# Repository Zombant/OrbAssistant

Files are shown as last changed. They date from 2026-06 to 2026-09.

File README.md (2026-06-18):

# Orb Assistant

This device is intended to be used with Home Assistant as an Assist Satellite entity. It includes a virtual switch to turn off the assistant (which can prevent midnight jumpscares). In this case you can just use it as a cool RGB light.

### Home Assistant setup

Some setup is required on home assistant

1. Add the ESPHome device (ESPHome has instructions)

2. Create an automation called _Restore Orb LED_ and insert the contents of restore_orb_led.yaml.

3. Create a script called _Store Current Orb LED_ and insert the contents of _store_current_orb_led.yaml_.

4. Create a voice assistant pipeline:
    1. Choose a conversation agent, STT, and TTS. I used Gemini (yes I know)
    2. Install the openwakeword app and add the service
    3. Copy _I_Ponder.tflite_ to _/share/openwakeword_. You may want to install the Terminal & SSH app to do this
    4. Alternatively you can train your own wake word with this [notebook](https://colab.research.google.com/drive/1q1oe2zOyZp7UsB3jJiQ1IFn8z5YfjwEb?usp=sharing)
5. For the orb personality, I added this text (partially AI generated) to the voice assistant instructions:
```
You are a voice assistant for Home Assistant.
Answer questions about the world truthfully.
Answer in plain text. Keep it simple and to the point.
You will also take the personality of a mystical orb/crystal ball. Your name is the "Orb of Nirud". You will not mention home assistant as that breaks the immersion. Instead, you are here to aid me in my wizard tower.

CRITICAL RULE FOR FALSE ACTIVATIONS:
The Speech-to-Text engine frequently picks up background noise and hallucinates phrases when the user hasn't actually spoken. If the user's input is very short and lacks a clear command or question (for example: "Thank you.", "Okay.", "Yeah.", "Hello.", or empty space), assume it was a false activation.

If you suspect a false activation, DO NOT greet the user. DO NOT ask how you can help. DO NOT use any question marks. You must respond with exactly: "False alarm." or "I didn't catch that." The conversation has ended
```

### BOM
- 1x INMP441 I2S Microphone
- 1x ESP32-C3-Super Mini
- 1x MAX98357A I2S Class D Amplifier
- 1x 3W 4Ohm Speaker
- 1x WS2812B RGB LED Ring (12 bits) [Link](https://www.amazon.com/dp/B0B2D69NQ4)
- 1x 3D-printed frame
- 1x 3D-printed LED cradle
- 1x Frosted glass light globe

### Construction
I soldered wires to the LED ring before pushing it into the LED cradle.

Everything is soldered to a standard perfboard.

I shoved everything in the base with the speaker pointed downward over the hole and the microphone angled towards a set of small holes.

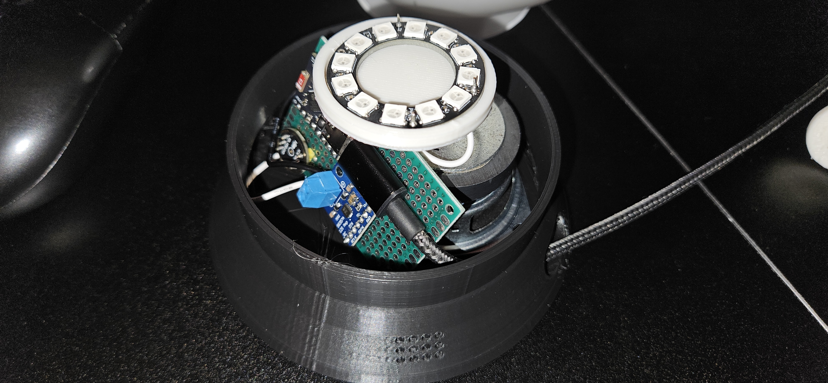
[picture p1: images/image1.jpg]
Inside the orb


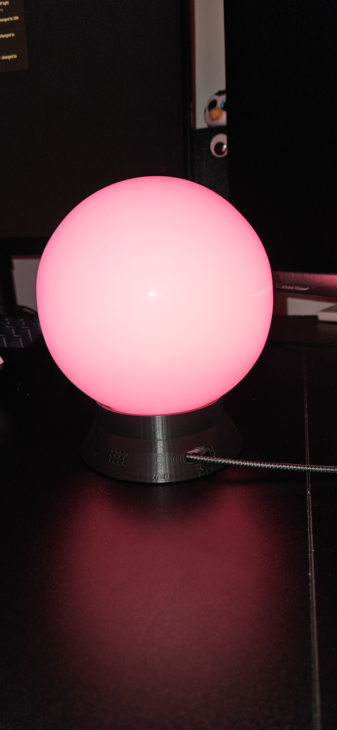
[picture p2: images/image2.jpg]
The orb


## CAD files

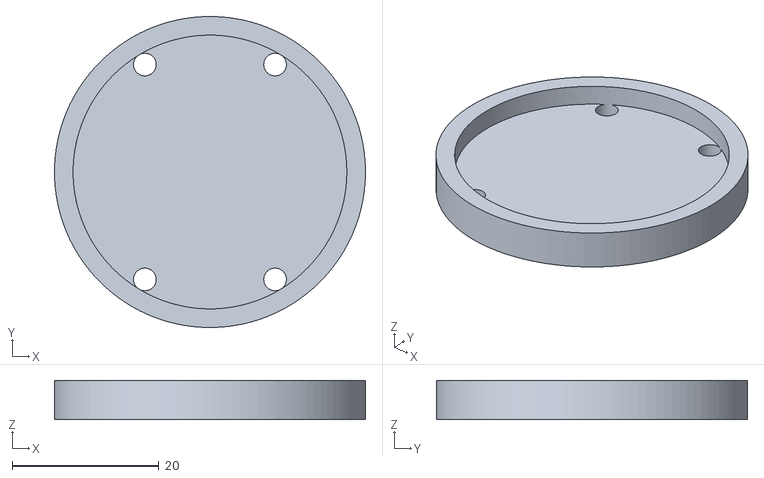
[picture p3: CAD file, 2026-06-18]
STLs/Orb_Cradle.stl
42.4 x 42.4 x 5.33

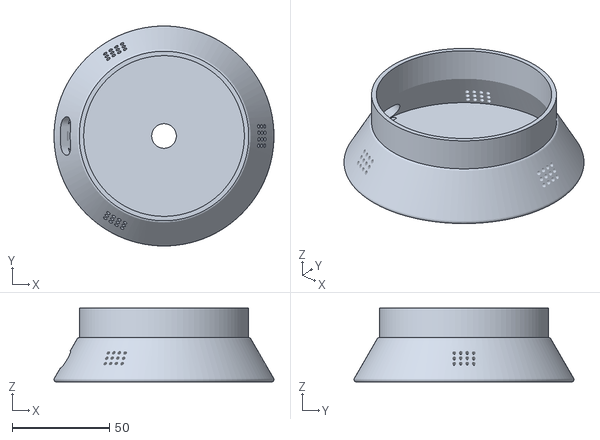
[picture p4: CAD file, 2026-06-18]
STLs/Orb_Frame_Tall_Flat.stl
113.3 x 113.3 x 38.1

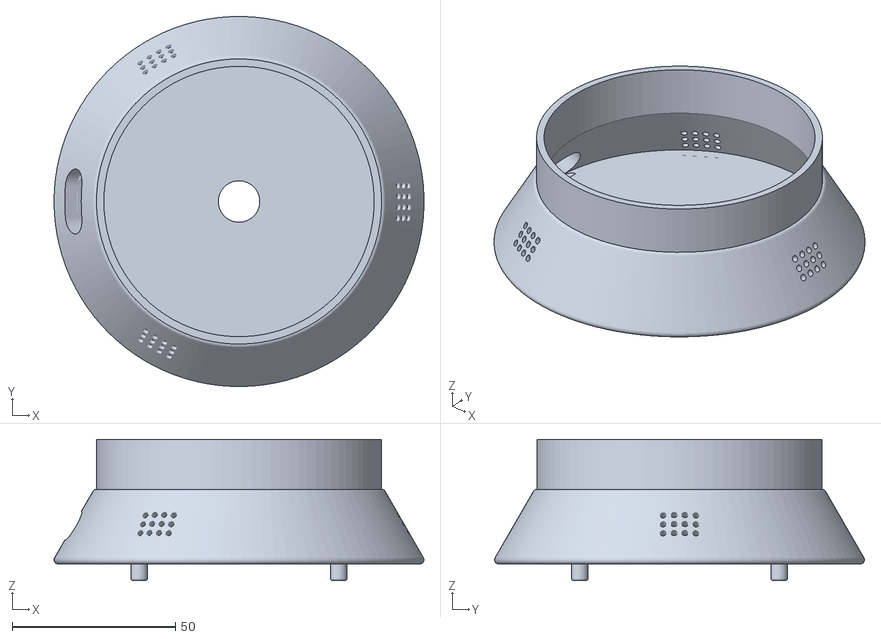
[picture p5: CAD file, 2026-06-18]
STLs/Orb_Frame_Tall.stl
113.3 x 113.3 x 43.2

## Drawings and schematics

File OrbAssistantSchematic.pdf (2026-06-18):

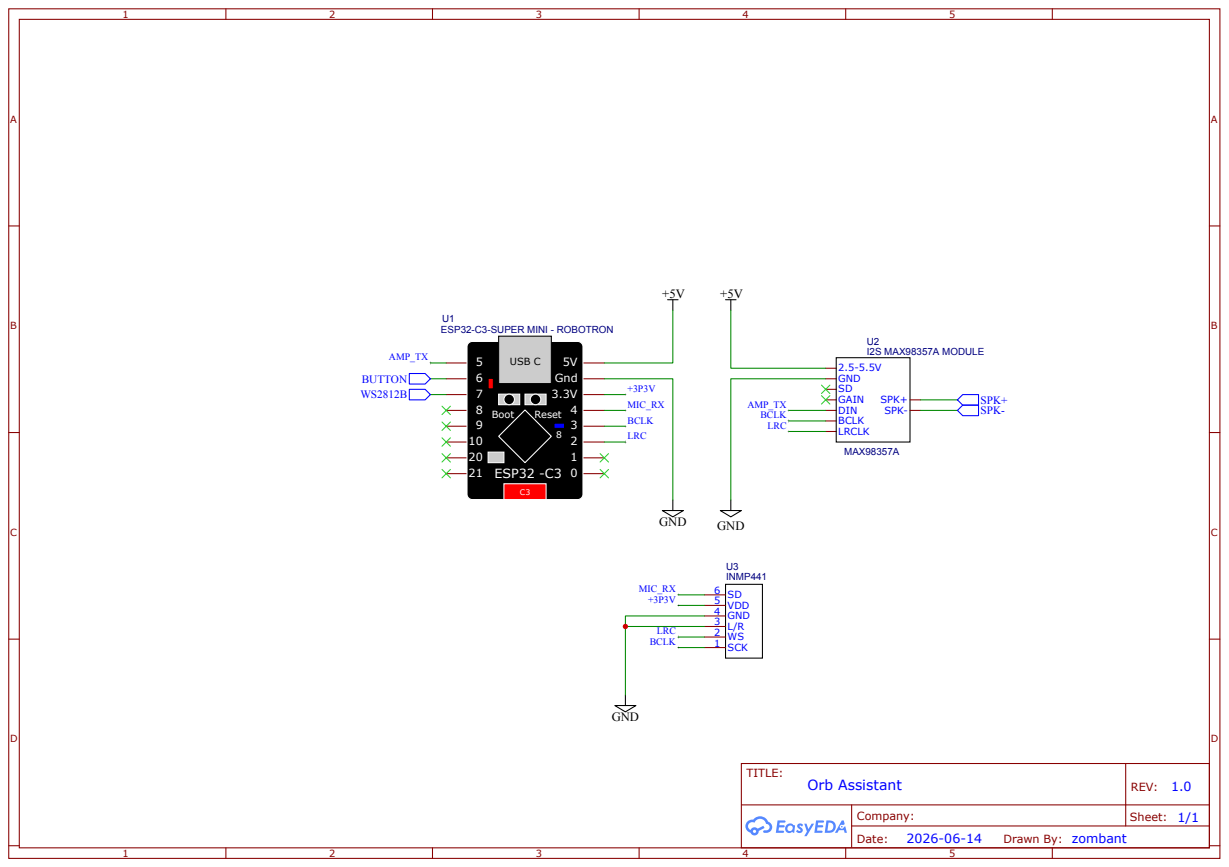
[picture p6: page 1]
TITLE:; Orb Assistant; REV: 1.0; Date:; Sheet: 1/1; Company:; GND; ESP32 -C3; USB C; Gnd; ResetBoot; I2S MAX98357A MODULE; MAX98357A; LRCLK; BCLK; DIN; GAIN; SPK-; SPK+; INMP441; L/R 3 WS 2 SCK 1; SD 6 VDD 5 GND 4; LRC; MIC_RX; BCLK LRC; AMP_TX; BUTTON

ESP32-C3-SUPER MINI - ROBOTRON

Drawn By: zombant

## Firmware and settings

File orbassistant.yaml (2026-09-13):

esphome:
  name: orbassistant
  friendly_name: OrbAssistant
  on_boot:
    - priority: -100
      then:
        - wait_until: api.connected
        - delay: 1s
        - voice_assistant.start_continuous:
        - if:
            condition:
              switch.is_on: voice_assistant_enabled
            then:
              - voice_assistant.start_continuous:

esp32:
  board: esp32-c3-devkitm-1
  framework:
    type: esp-idf

# Enable logging
logger:

# Enable Home Assistant API
api:
  encryption:
    key: "CLxz81cTP03mfKIvN7Z84Y10ydo16ZOyvr8NOj1zFlY="

ota:
  - platform: esphome
    password: "2b2f0fbe0b58ab80040c117297f95868"

wifi:
  ssid: !secret wifi_ssid
  password: !secret wifi_password
  power_save_mode: none

  # Enable fallback hotspot (captive portal) in case wifi connection fails
  ap:
    ssid: "Orbassistant Fallback Hotspot"
    password: "xQpKBtD6AhAt"

captive_portal:
  

i2s_audio:
  - id: i2s_hub
    i2s_lrclk_pin: GPIO2
    i2s_bclk_pin: GPIO3

microphone:
  - platform: i2s_audio
    id: esp32_mic
    i2s_audio_id: i2s_hub
    i2s_din_pin: GPIO4
    adc_type: external
    pdm: false
    channel: left
    on_data:
      - logger.log:
          format: "Mic data received: %d bytes"
          args: ['x.size()']

speaker:
  - platform: i2s_audio
    id: esp32_speaker
    i2s_audio_id: i2s_hub
    i2s_dout_pin: GPIO5
    dac_type: external

light:
  - platform: esp32_rmt_led_strip
    channel_colors: GRB
    id: assistant_led
    name: "Orb Assistant LED"
    pin: GPIO7
    num_leds: 12          
    chipset: WS2812
    effects:
      - pulse:
          name: Breathing
          transition_length: 1s
          update_interval: 1s
      - pulse:
          name: Slow Pulse
          transition_length: 250ms
          update_interval: 250ms
          min_brightness: 50%
          max_brightness: 100%
      - pulse:
          name: Fast Pulse
          transition_length: 100ms
          update_interval: 100ms
          min_brightness: 50%
          max_brightness: 100%
      - pulse:
          name: Slow Pulse Night
          transition_length: 250ms
          update_interval: 250ms
          min_brightness: 20%
          max_brightness: 35%
      - pulse:
          name: Fast Pulse Night
          transition_length: 100ms
          update_interval: 100ms
          min_brightness: 20%
          max_brightness: 35%
      - addressable_rainbow:
          name: Rainbow Sweep Fast
          speed: "60"
          width: "50"
      - addressable_rainbow:
          name: Rainbow Sweep Slow
          speed: "10"
          width: "50"
      - flicker:
          name: Flicker
          alpha: "0.95"
          intensity: "0.015"
binary_sensor:
  - platform: gpio
    pin:
      number: GPIO6
      mode:
        input: true
        pullup: true
      inverted: true
    name: "Reset Button"
    on_press:
      - voice_assistant.stop
      - delay: 1s
      - voice_assistant.start_continuous:
  
voice_assistant:
  id: orb_voice_assistant
  microphone: esp32_mic
  speaker: esp32_speaker
  noise_suppression_level: 2
  use_wake_word: true

  on_wake_word_detected:
    then:
      - homeassistant.action:
          action: script.store_current_orb_led
      - if:
          condition:
            switch.is_on: night_mode
          then:
            - light.turn_on:
                id: assistant_led
                blue: 100%
                red: 0%
                green: 100%
                brightness: 20%
                effect: Fast Pulse Night
          else:
            - light.turn_on:
                id: assistant_led
                blue: 100%
                red: 0%
                green: 100%
                brightness: 100%
                effect: Fast Pulse
      - logger.log: on_wake_word_detected

  on_listening:
    - if:
        condition:
          switch.is_on: night_mode
        then:
          - light.turn_on:
              id: assistant_led
              blue: 100%
              red: 0%
              green: 0%
              brightness: 25%
              effect: none
        else:
          - light.turn_on:
              id: assistant_led
              blue: 100%
              red: 0%
              green: 0%
              brightness: 100%
              effect: "Slow Pulse"
    - logger.log:
          format: "on_listening"

  on_stt_vad_end:
    - if:
        condition:
          switch.is_on: night_mode
        then:
          - light.turn_on:
              id: assistant_led
              blue: 0%
              red: 0%
              green: 100%
              brightness: 25%
              effect: none
        else:
          - light.turn_on:
              id: assistant_led
              blue: 100%
              red: 0%
              green: 0%
              brightness: 100%
              effect: "Fast Pulse"
    - logger.log:
          format: "on_stt_vad_end"
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
